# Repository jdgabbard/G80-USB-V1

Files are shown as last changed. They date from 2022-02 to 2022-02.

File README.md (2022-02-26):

# G80-USB V1
 G80-USB v1.0 SBC

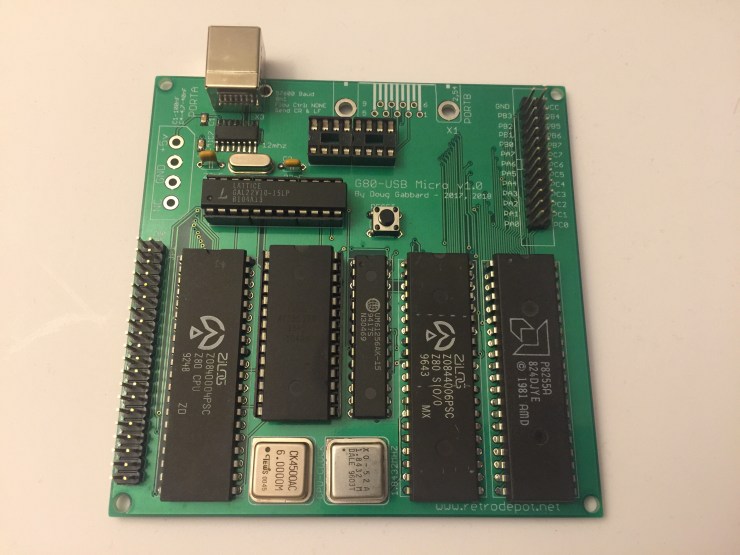
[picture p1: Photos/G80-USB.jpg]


The G80-USB Micro SBC.  The second iteration of the G80 Computer family, this computer made a change to it's communication by allowing for RS-232 or USB Serial interfaces to communicate with the computer.

The source code for the firmware can be found here: https://github.com/jdgabbard/z80-G-DOS

Or you can download previous version of the software in the downloads section of my website:  www.retrodepot.net

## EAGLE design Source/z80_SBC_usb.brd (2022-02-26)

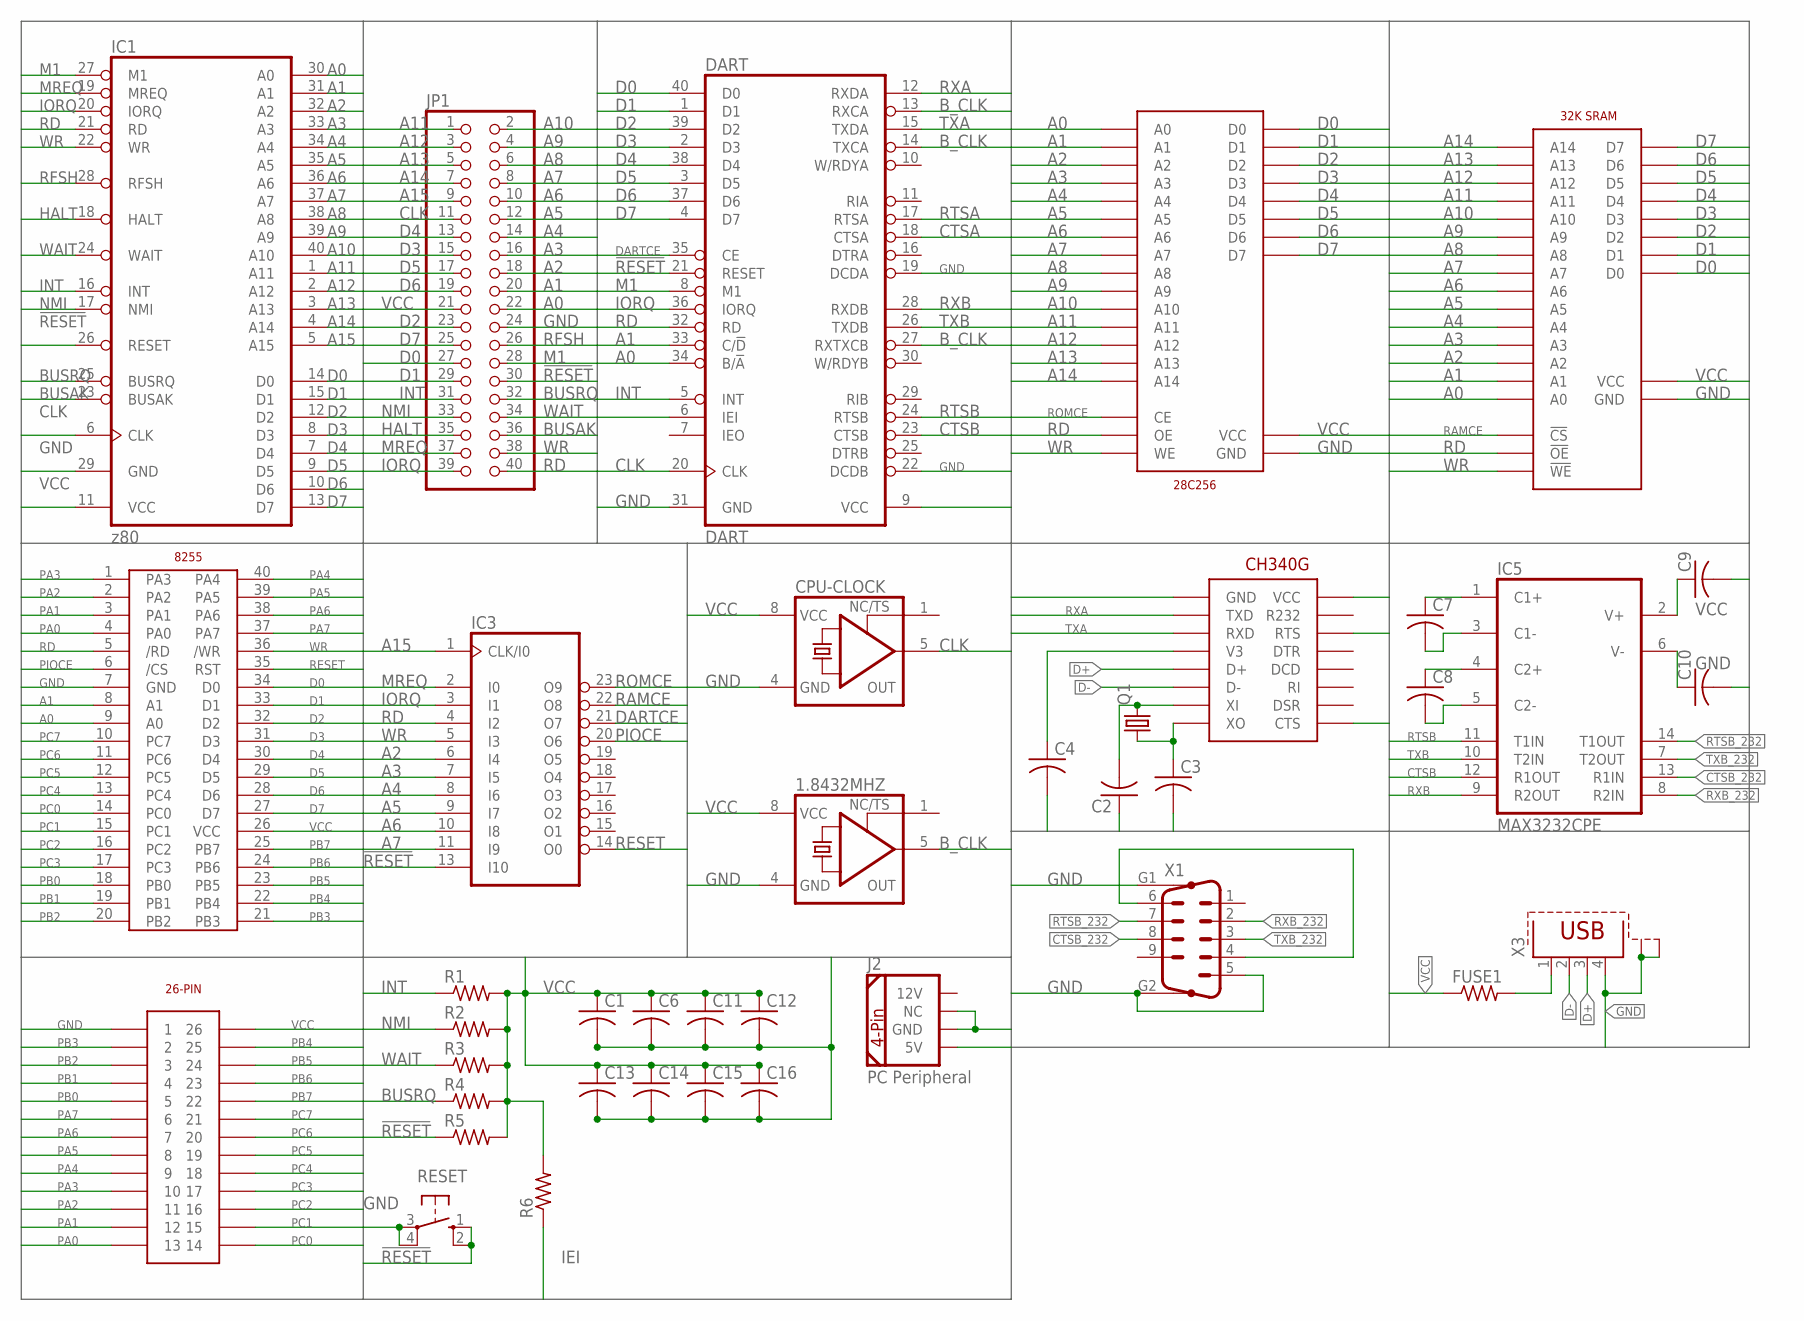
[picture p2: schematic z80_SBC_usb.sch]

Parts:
1.8432MHZ: XO-8; DIL08S
28C256: 28C256; DIP28
C1, C4, C6, C7, C8, C9, C10, C11, C12, C13, C14, C15, C16: C-USC0805; C0805
C2, C3: C-US050-024X044; C050-024X044
CPU-CLOCK: XO-8; DIL08S
DART: DART; DIL40
FUSE1: R-US_R1206W; R1206W
IC1: z80; DIL40
IC3: 22V10; DIL24-3
IC4: 8255
IC5: MAX3232CPE; DIL16
IC6: 32K SRAM; DIP28-300
IC7: CH340G; SO16
J1: SOCKET-DIP26
J2: PC Peripheral; COMPUTER-PERIPHERAL-POWER
JP1: PINHD-2X20; 2X20
Q1: CRYSTALHC49S; HC49/S
R1, R2, R3, R4, R5, R6: R-US_M0805; M0805
RESET: 10-XX; B3F-10XX
X1: M09HP
X3: PN61729-S

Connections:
!RESET: DART.21 (RESET), IC1.26 (RESET), IC3.13 (I10), JP1.30, R5.1, RESET.1 (S), RESET.2 (S1)
A0: 28C256.P$10 (A0), DART.34 (B/!A), IC1.30 (A0), IC4.9 (A0), IC6.P$10 (A0), JP1.22
A1: 28C256.P$9 (A1), DART.33 (C/!D), IC1.31 (A1), IC4.8 (A1), IC6.P$9 (A1), JP1.20
A2: 28C256.P$8 (A2), IC1.32 (A2), IC3.6 (I4), IC6.P$8 (A2), JP1.18
A3: 28C256.P$7 (A3), IC1.33 (A3), IC3.7 (I5), IC6.P$7 (A3), JP1.16
A4: 28C256.P$6 (A4), IC1.34 (A4), IC3.8 (I6), IC6.P$6 (A4), JP1.14
A5: 28C256.P$5 (A5), IC1.35 (A5), IC3.9 (I7), IC6.P$5 (A5), JP1.12
A6: 28C256.P$4 (A6), IC1.36 (A6), IC3.10 (I8), IC6.P$4 (A6), JP1.10
A7: 28C256.P$3 (A7), IC1.37 (A7), IC3.11 (I9), IC6.P$3 (A7), JP1.8
A8: 28C256.P$25 (A8), IC1.38 (A8), IC6.P$25 (A8), JP1.6
A9: 28C256.P$24 (A9), IC1.39 (A9), IC6.P$24 (A9), JP1.4
A10: 28C256.P$21 (A10), IC1.40 (A10), IC6.P$21 (A10), JP1.2
A11: 28C256.P$23 (A11), IC1.1 (A11), IC6.P$23 (A11), JP1.1
A12: 28C256.P$2 (A12), IC1.2 (A12), IC6.P$2 (A12), JP1.3
A13: 28C256.P$26 (A13), IC1.3 (A13), IC6.P$26 (A13), JP1.5
A14: 28C256.P$1 (A14), IC1.4 (A14), IC6.P$1 (A14), JP1.7
A15: IC1.5 (A15), IC3.1 (CLK/I0), JP1.9
BUSAK: IC1.23 (BUSAK), JP1.36
BUSRQ: IC1.25 (BUSRQ), JP1.32, R4.1
B_CLK: 1.8432MHZ.5 (OUT), DART.13 (RXCA), DART.14 (TXCA), DART.27 (RXTXCB)
CLK: CPU-CLOCK.5 (OUT), DART.20 (CLK), IC1.6 (CLK), JP1.11
CTSA: DART.18 (CTSA), IC7.14 (RTS)
CTSB: DART.23 (CTSB), IC5.12 (R1OUT)
CTSB_232: IC5.13 (R1IN), X1.8
D0: 28C256.P$11 (D0), DART.40 (D0), IC1.14 (D0), IC4.34 (D0), IC6.P$11 (D0), JP1.27
D1: 28C256.P$12 (D1), DART.1 (D1), IC1.15 (D1), IC4.33 (D1), IC6.P$12 (D1), JP1.29
D2: 28C256.P$13 (D2), DART.39 (D2), IC1.12 (D2), IC4.32 (D2), IC6.P$13 (D2), JP1.23
D3: 28C256.P$15 (D3), DART.2 (D3), IC1.8 (D3), IC4.31 (D3), IC6.P$15 (D3), JP1.15
D4: 28C256.P$16 (D4), DART.38 (D4), IC1.7 (D4), IC4.30 (D4), IC6.P$16 (D4), JP1.13
D5: 28C256.P$17 (D5), DART.3 (D5), IC1.9 (D5), IC4.29 (D5), IC6.P$17 (D5), JP1.17
D6: 28C256.P$18 (D6), DART.37 (D6), IC1.10 (D6), IC4.28 (D6), IC6.P$18 (D6), JP1.19
D7: 28C256.P$19 (D7), DART.4 (D7), IC1.13 (D7), IC4.27 (D7), IC6.P$19 (D7), JP1.25
D+: IC7.5 (D+), X3.3
D-: IC7.6 (D-), X3.2
DARTCE: DART.35 (CE), IC3.21 (O7)
GND: 1.8432MHZ.4 (GND), 28C256.P$14 (GND), C1.2, C2.1, C3.2, C4.2, C6.2, C10.2, C11.2, C12.2, C13.2, C14.2, C15.2, C16.2, CPU-CLOCK.4 (GND), DART.19 (DCDA), DART.22 (DCDB), DART.31 (GND), IC1.29 (GND), IC3.12 (GND), IC4.7 (GND), IC5.15 (GND), IC6.P$14 (GND), IC7.1 (GND), J1.P$1 (1), J2.GND, J2.NC, JP1.24, RESET.3, RESET.4 (P1), X1.5, X1.G1, X1.G2, X3.4, X3.S1, X3.S2
HALT: IC1.18 (HALT), JP1.35
IEI: DART.6 (IEI), R6.1
INT: DART.5 (INT), IC1.16 (INT), JP1.31, R1.1
IORQ: DART.36 (IORQ), IC1.20 (IORQ), IC3.3 (I1), JP1.39
M1: DART.8 (M1), IC1.27 (M1), JP1.28
MREQ: IC1.19 (MREQ), IC3.2 (I0), JP1.37
unnamed: C7.1, IC5.1 (C1+)
unnamed: C8.1, IC5.4 (C2+)
unnamed: C8.2, IC5.5 (C2-)
unnamed: C7.2, IC5.3 (C1-)
unnamed: C9.1, IC5.2 (V+)
unnamed: C10.1, IC5.6 (V-)
unnamed: C2.2, IC7.7 (XI), Q1.2
unnamed: C3.1, IC7.8 (XO), Q1.1
unnamed: FUSE1.2, X3.1
unnamed: C4.1, IC7.4 (V3)
unnamed: X1.4, X1.6
NMI: IC1.17 (NMI), JP1.33, R2.1
PA0: IC4.4 (PA0), J1.P$13 (13)
PA1: IC4.3 (PA1), J1.P$12 (12)
PA2: IC4.2 (PA2), J1.P$11 (11)
PA3: IC4.1 (PA3), J1.P$10 (10)
PA4: IC4.40 (PA4), J1.P$9 (9)
PA5: IC4.39 (PA5), J1.P$8 (8)
PA6: IC4.38 (PA6), J1.P$7 (7)
PA7: IC4.37 (PA7), J1.P$6 (6)
PB0: IC4.18 (PB0), J1.P$5 (5)
PB1: IC4.19 (PB1), J1.P$4 (4)
PB2: IC4.20 (PB2), J1.P$3 (3)
PB3: IC4.21 (PB3), J1.P$2 (2)
PB4: IC4.22 (PB4), J1.P$25 (25)
PB5: IC4.23 (PB5), J1.P$24 (24)
PB6: IC4.24 (PB6), J1.P$23 (23)
PB7: IC4.25 (PB7), J1.P$22 (22)
PC0: IC4.14 (PC0), J1.P$14 (14)
PC1: IC4.15 (PC1), J1.P$15 (15)
PC2: IC4.16 (PC2), J1.P$16 (16)
PC3: IC4.17 (PC3), J1.P$17 (17)
PC4: IC4.13 (PC4), J1.P$18 (18)
PC5: IC4.12 (PC5), J1.P$19 (19)
PC6: IC4.11 (PC6), J1.P$20 (20)
PC7: IC4.10 (PC7), J1.P$21 (21)
PIOCE: IC3.20 (O6), IC4.6 (/CS)
RAMCE: IC3.22 (O8), IC6.P$20 (!CS)
RD: 28C256.P$22 (OE), DART.32 (RD), IC1.21 (RD), IC3.4 (I2), IC4.5 (/RD), IC6.P$22 (!OE), JP1.40
RESET: IC3.14 (O0), IC4.35 (RST)
RFSH: IC1.28 (RFSH), JP1.26
ROMCE: 28C256.P$20 (CE), IC3.23 (O9)
RTSA: DART.17 (RTSA), IC7.9 (CTS)
RTSB: DART.24 (RTSB), IC5.11 (T1IN)
RTSB_232: IC5.14 (T1OUT), X1.7
RXA: DART.12 (RXDA), IC7.2 (TXD)
RXB: DART.28 (RXDB), IC5.9 (R2OUT)
RXB_232: IC5.8 (R2IN), X1.2
TXA: DART.15 (TXDA), IC7.3 (RXD)
TXB: DART.26 (TXDB), IC5.10 (T2IN)
TXB_232: IC5.7 (T2OUT), X1.3
VCC: 1.8432MHZ.8 (VCC), 28C256.P$28 (VCC), C1.1, C6.1, C9.2, C11.1, C12.1, C13.1, C14.1, C15.1, C16.1, CPU-CLOCK.8 (VCC), DART.9 (VCC), FUSE1.1, IC1.11 (VCC), IC3.24 (VCC), IC4.26 (VCC), IC5.16 (VCC), IC6.P$28 (VCC), IC7.16 (VCC), J1.P$26 (26), J2.5V, JP1.21, R1.2, R2.2, R3.2, R4.2, R5.2, R6.2
WAIT: IC1.24 (WAIT), JP1.34, R3.1
WR: 28C256.P$27 (WE), IC1.22 (WR), IC3.5 (I3), IC4.36 (/WR), IC6.P$27 (!WE), JP1.38

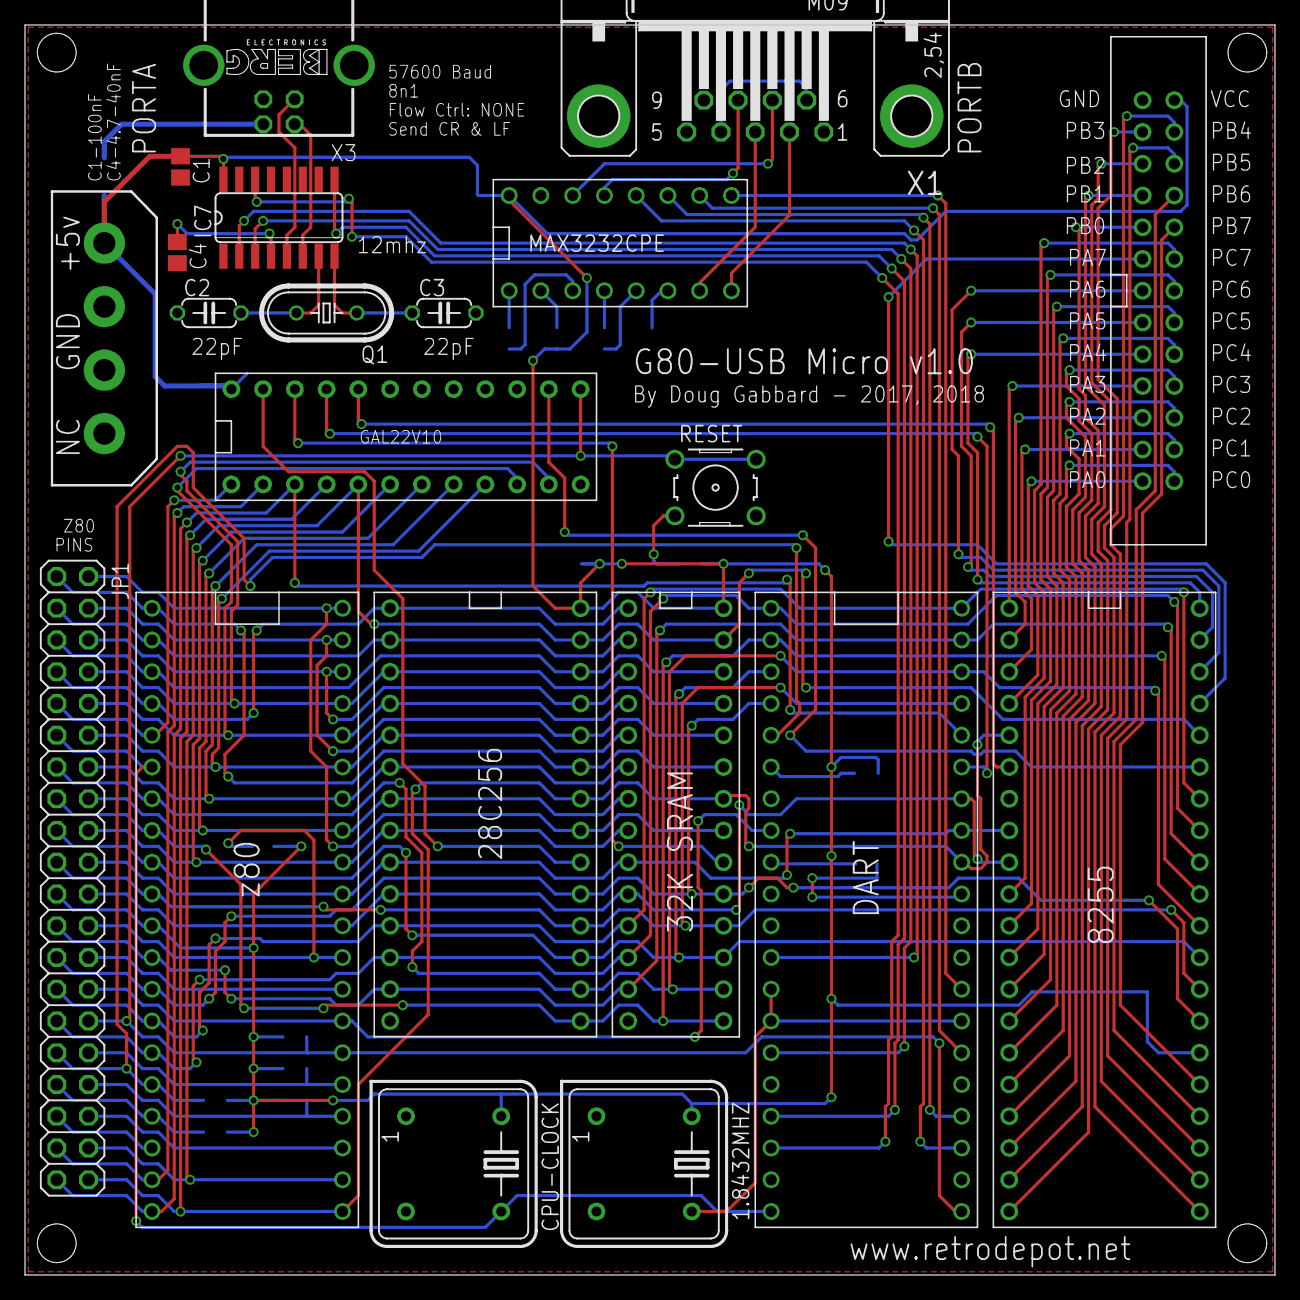
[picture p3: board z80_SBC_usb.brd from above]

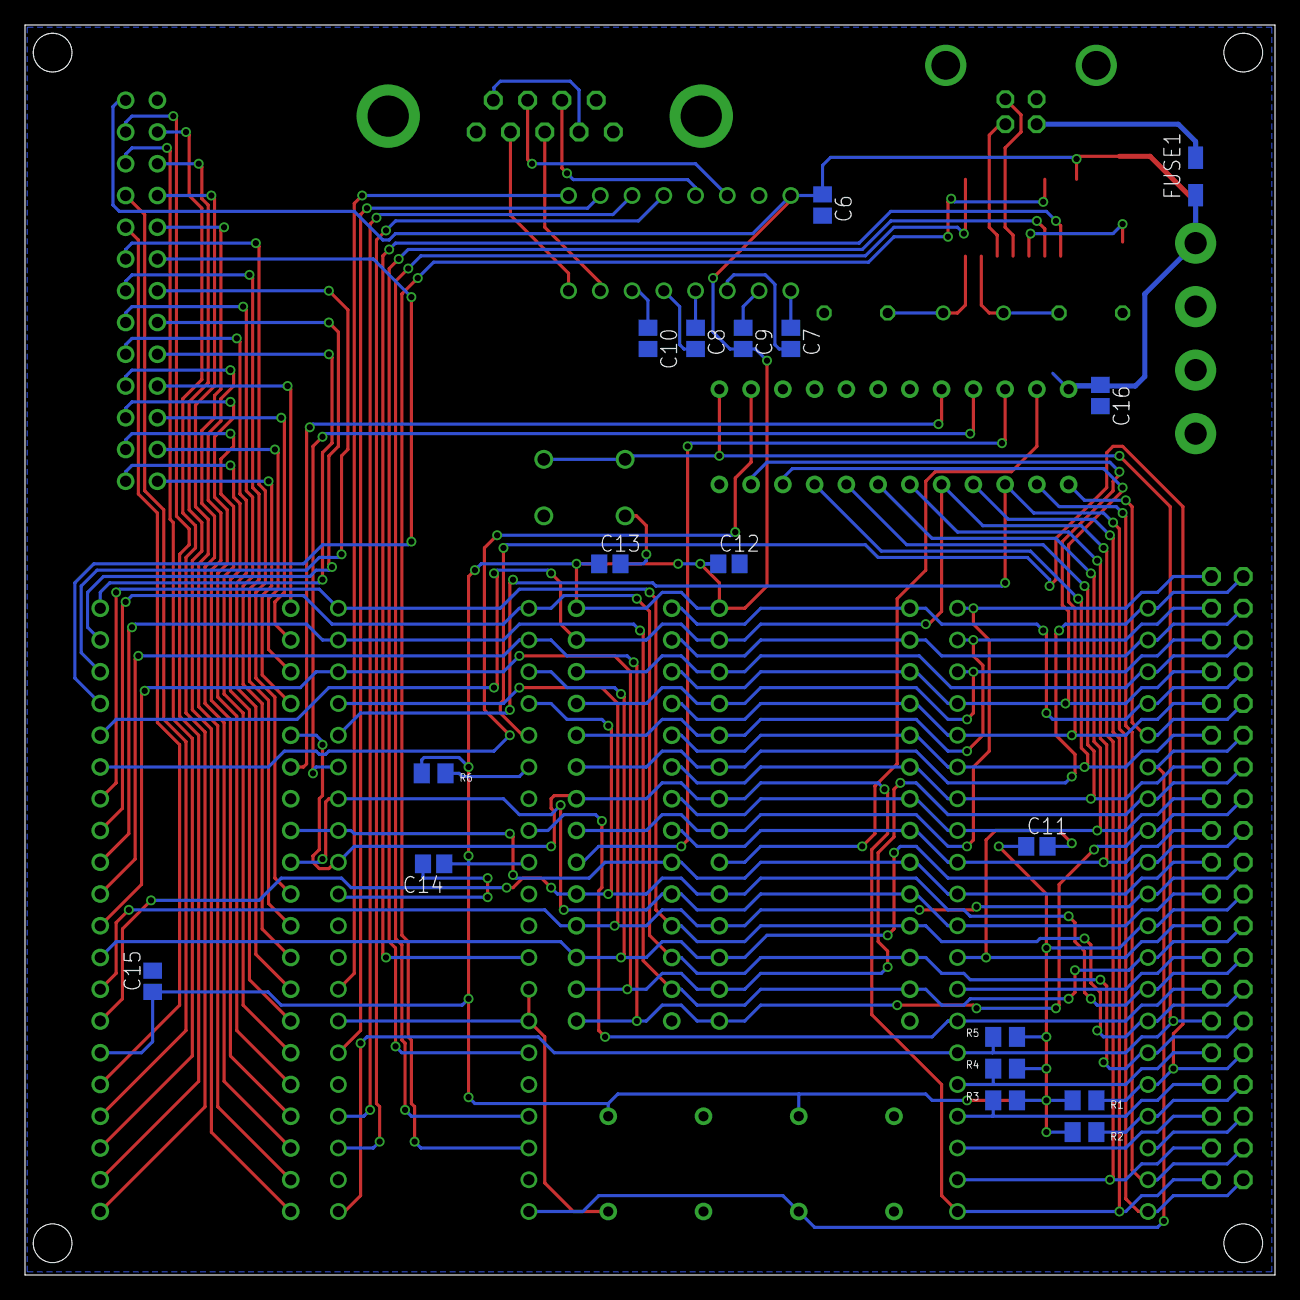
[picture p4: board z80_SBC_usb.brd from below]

Board: 2 copper layers, 100.0 x 100.0 mm, 39 parts (18 on the bottom side), 96 nets.

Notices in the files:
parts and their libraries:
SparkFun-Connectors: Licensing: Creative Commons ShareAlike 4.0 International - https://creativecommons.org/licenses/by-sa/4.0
